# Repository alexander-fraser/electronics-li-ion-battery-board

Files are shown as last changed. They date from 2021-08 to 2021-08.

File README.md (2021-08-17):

# electronics-li-ion-battery-board
A protected li-ion battery board to connect 18650 cells to projects.

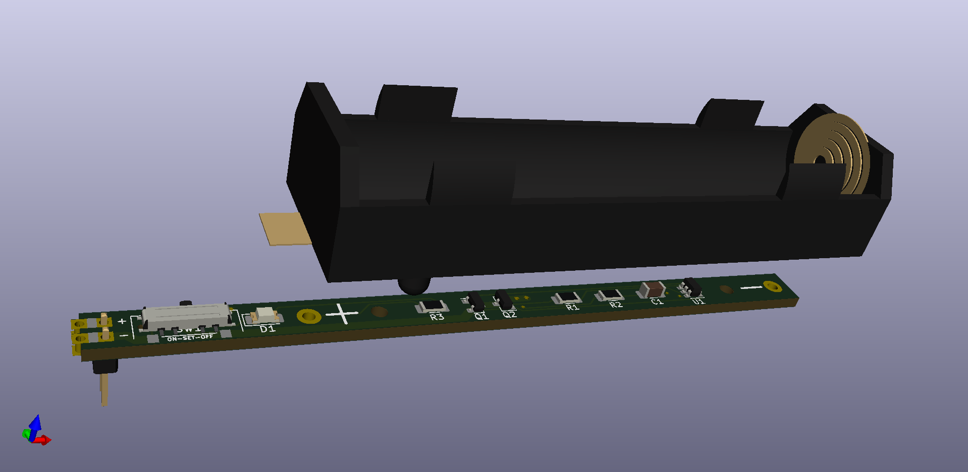
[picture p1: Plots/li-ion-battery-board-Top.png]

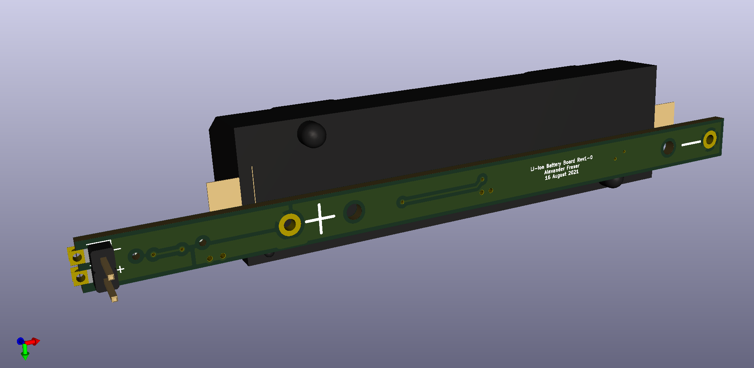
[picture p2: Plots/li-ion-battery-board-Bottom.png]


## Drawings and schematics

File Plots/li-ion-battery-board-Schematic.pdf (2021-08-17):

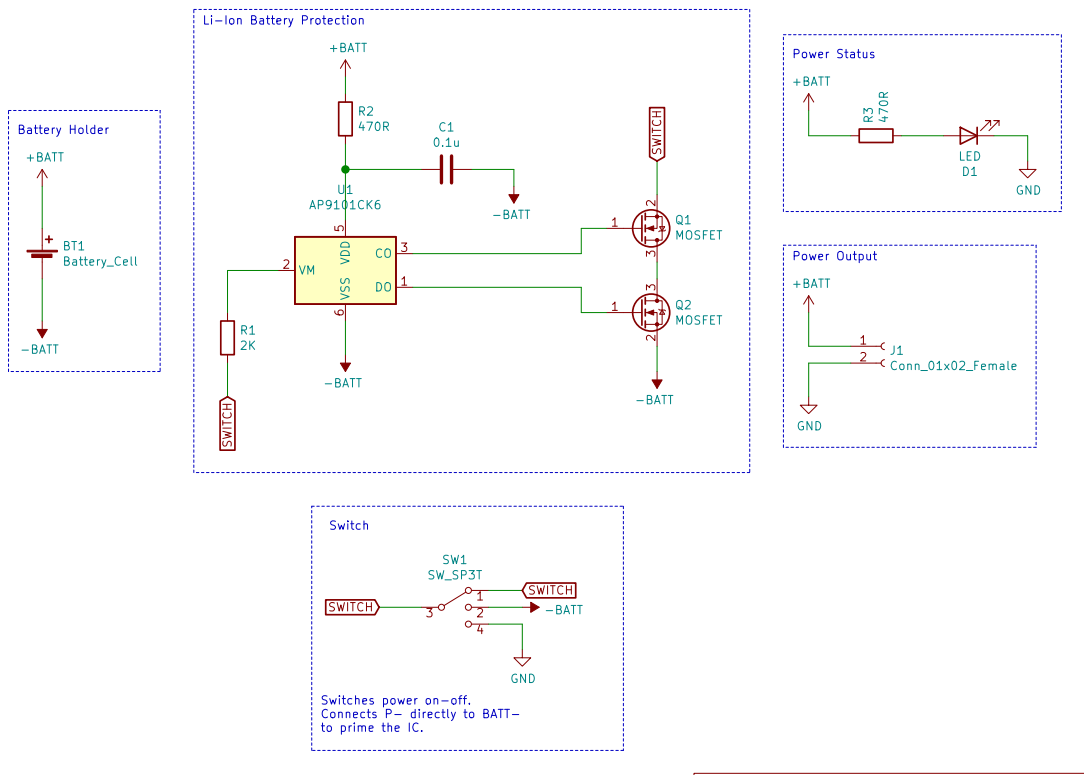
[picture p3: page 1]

File: li-ion-battery-board.sch Sheet: / GND

Connects P- directly to BATT-
to prime the IC.

Li-Ion 18650 Battery Board

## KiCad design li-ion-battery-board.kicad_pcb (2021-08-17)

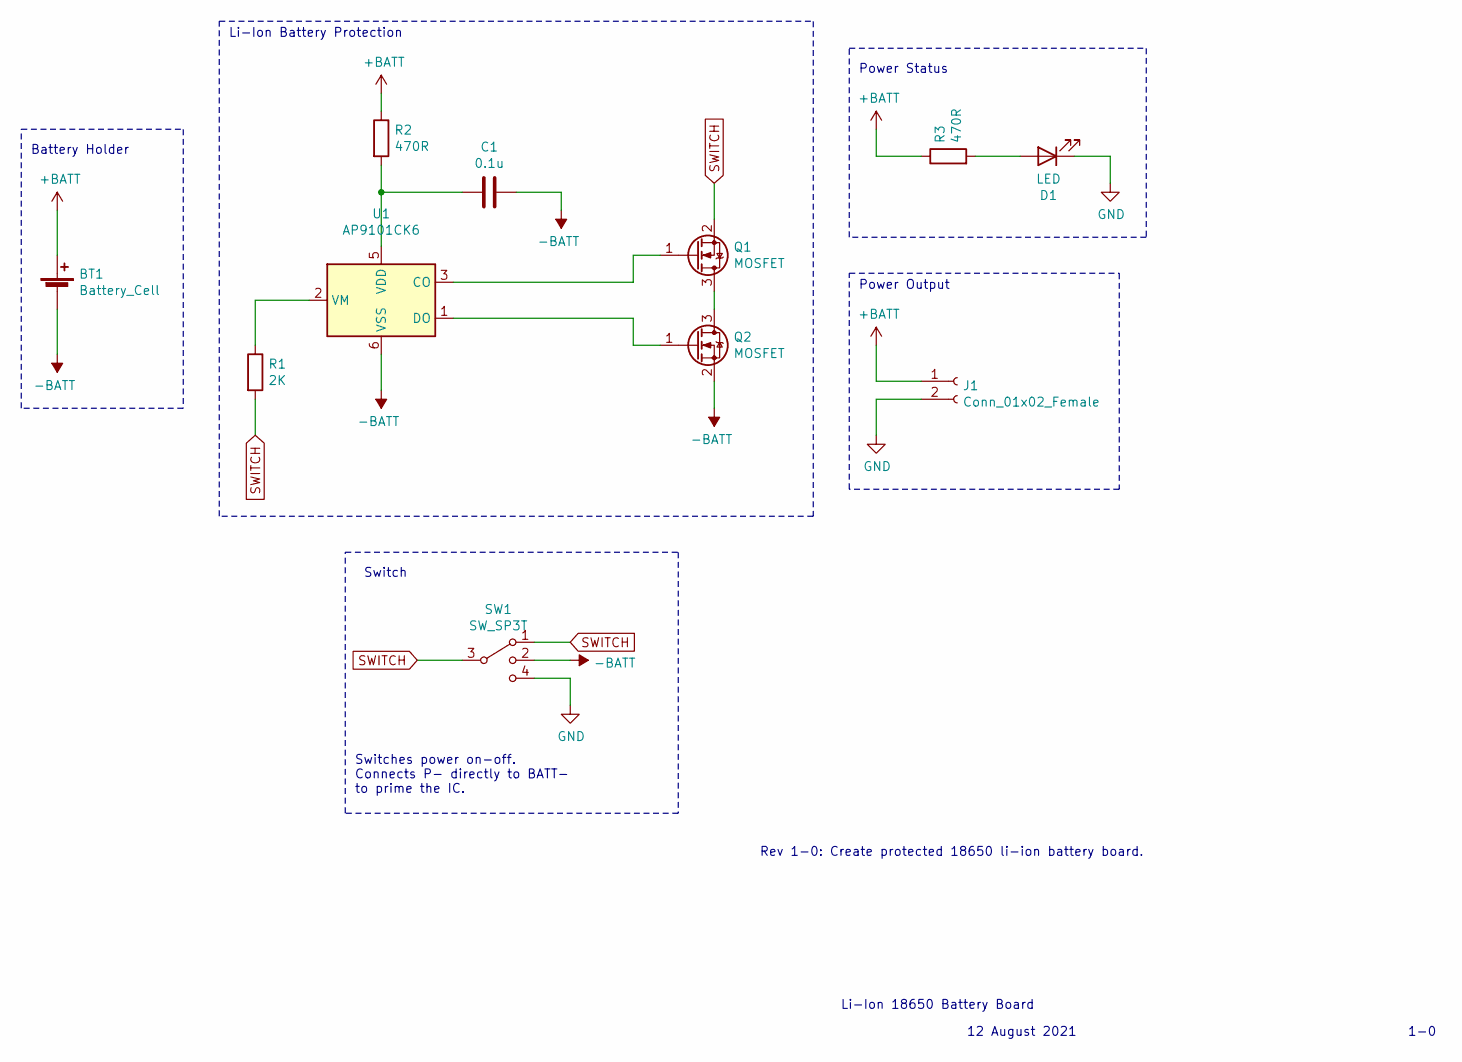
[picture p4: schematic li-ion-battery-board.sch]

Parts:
BT1: Battery_Cell; BatteryHolder_CZK_1x18650
C1: 0.1u; C_1206_3216Metric_Pad1.33x1.80mm_HandSolder
D1: LED; LED_1206_3216Metric_Castellated
J1: Conn_01x02_Female; Castellation_1x02_P2.54mm_Vertical
Q1, Q2: MOSFET; SOT-23
R1: 2K; R_1206_3216Metric_Pad1.30x1.75mm_HandSolder
R2, R3: 470R; R_1206_3216Metric_Pad1.30x1.75mm_HandSolder
SW1: SW_SP3T; SW_SP3T_Nidec_CL_SB_13B
U1: AP9101CK6; SOT-23-6

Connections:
+BATT: BT1.1 (+), J1.1, R2.1, R3.1
-BATT: BT1.2 (-), C1.1, Q2.2 (S), SW1.2, U1.6 (VSS)
GND: D1.1 (K), J1.2, SW1.4
unnamed: C1.2, R2.2, U1.5 (VDD)
unnamed: D1.2 (A), R3.2
unnamed: Q1.1 (G), U1.3 (CO)
unnamed: Q1.3 (D), Q2.3 (D)
unnamed: Q2.1 (G), U1.1 (DO)
unnamed: R1.1, U1.2 (VM)
SWITCH: Q1.2 (S), R1.2, SW1.1, SW1.3

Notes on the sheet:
Li-Ion 18650 Battery Board
12 August 2021
1-0
Rev 1-0: Create protected 18650 li-ion battery board.
Li-Ion Battery Protection
Power Status
Power Output
Switch
Battery Holder
Switches power on-off. Connects P- directly to BATT- to prime the IC.

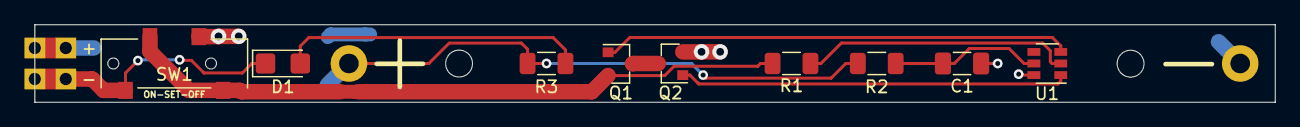
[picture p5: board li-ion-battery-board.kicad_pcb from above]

Board: 2 copper layers, 101.6 x 6.4 mm, 13 parts (1 on the bottom side), 10 nets.

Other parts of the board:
M1, M1#2: MountingHole_2.2mm_M2

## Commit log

2021-08-13 Create electrical schematic.
    [li-ion-battery-board.kicad_pcb, li-ion-battery-board.sch]
2021-08-14 Assign footprints in schematic.
    [li-ion-battery-board.sch]
2021-08-16 Change MOSFET pin and layout assignments.
    [li-ion-battery-board.sch]
2021-08-16 Complete PCB layout.
    [li-ion-battery-board.kicad_pcb, li-ion-battery-board.sch]
2021-08-17 Add mounting holes and modify silkscreen text.
    [li-ion-battery-board.kicad_pcb]
2021-08-17 Correct solder mask for castellations.
    [li-ion-battery-board.kicad_pcb]
